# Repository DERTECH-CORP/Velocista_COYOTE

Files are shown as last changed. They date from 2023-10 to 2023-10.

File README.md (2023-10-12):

# Velocista "Coyote" - Robot Seguidor de Línea

El_COYOTE_V1

## Descripción

El velocista "Coyote" es un robot seguidor de línea de alto rendimiento diseñado para competir en desafíos de velocidad y precisión. Este repositorio contiene el firmware, el diseño de hardware electrónico y los modelos 3D relacionados con el robot Coyote. Aquí encontrarás toda la información necesaria para comprender el robot seguidor de línea Coyote.

## Características principales

- **Seguimiento de línea preciso**: Coyote utiliza los sensores ópticos QRE1113 para seguir líneas con precisión y rapidez. Su firmware incorpora algoritmos de control PID que garantizan un seguimiento suave y estable.

- **Velocidad y agilidad**: Utiliza sus motores de RPM2000 con diseño aerodinámico, El Coyote puede alcanzar altas velocidades y realizar maniobras bruscas gracias a sus ruedas anchas que le ayudan a tener mejor agarre en la pista.

- **Firmware personalizable**: El firmware del robot está escrito en lenguaje C++ y se basa en la plataforma de desarrollo ESP32. Este micricontrolador nos ayuda mucho ya que tiene antena wifi/bluetooth integrada y gracias a eso podemos debuguear y calibrar el robot sin necesidad de conectarlo a la computadora.

## Contenido del repositorio

- **/firmware**: En esta carpeta encontrarás el código fuente del firmware utilizado en Coyote. El firmware está escrito en lenguaje C++ y se basa en la plataforma de desarrollo ESP32. Incluye los algoritmos de control, la lógica de seguimiento de línea y la comunicación con los sensores y actuadores del robot ademas de la interfaz bluetooth.

- **/hardware**: Aquí se encuentran los diseños y esquemas del hardware electrónico utilizado en Coyote. Estos archivos incluyen los esquemas de conexión y los diagramas de circuitos.

- **/3D**: En esta carpeta encontrarás los modelos 3D del robot Coyote. Se pueden utilizar para visualizar, modificar y fabricar las partes físicas del robot.

¡Gracias por tu interés en Coyote!

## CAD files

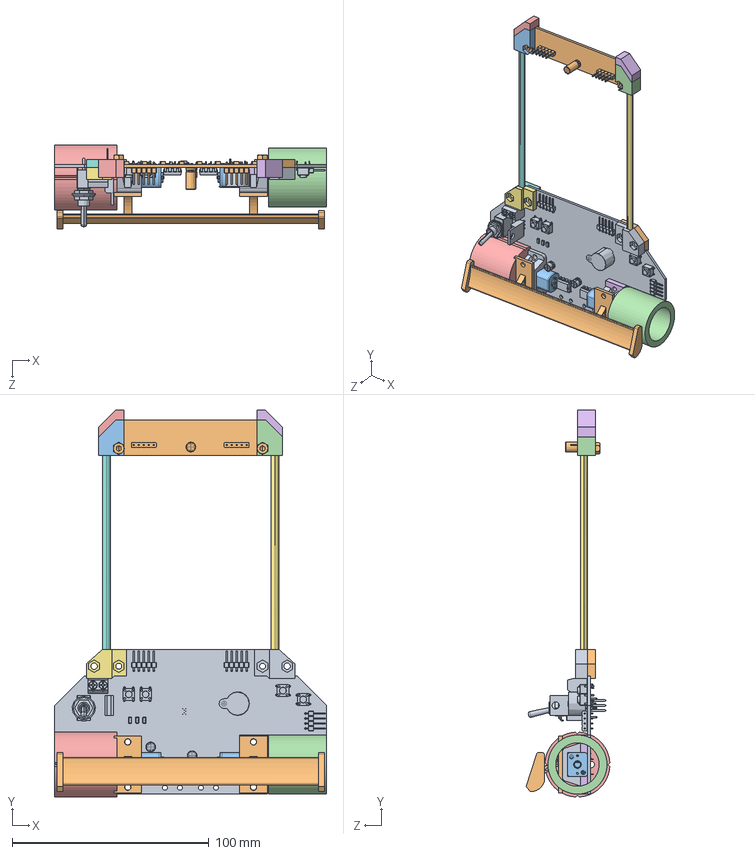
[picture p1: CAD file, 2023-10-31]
hardware_3D/COYOTE_V1.SLDASM
138.2 x 196.5 x 42.5 mm
PCB_Main_Board_COYOTE
PCB_QRE1113_Line_Sensors_x8
MicroMotor_2000RPM x 2
Cubierta_coyote x 2
Sop_VarillaDT
Sop_VarillaDB
Sop_VarillaIT
Sop_VarillaIB
Sop_SensoresD
Sop_SensoresI
Cabeza_VarillaD
Cabeza_VarillaI
VarillaI
VarillaD
Soporte_Pololu x 2
Aleron_Coyote

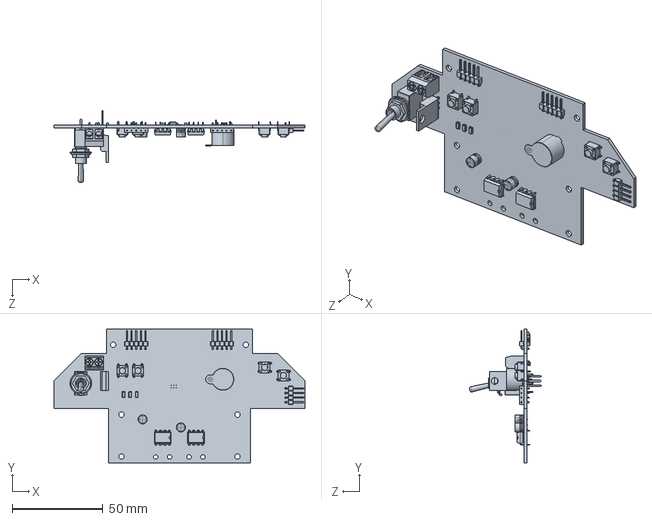
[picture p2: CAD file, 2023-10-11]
hardware_3D/PCB_Main_Board_COYOTE.SLDPRT
138.0 x 73.5 x 39.7 mm

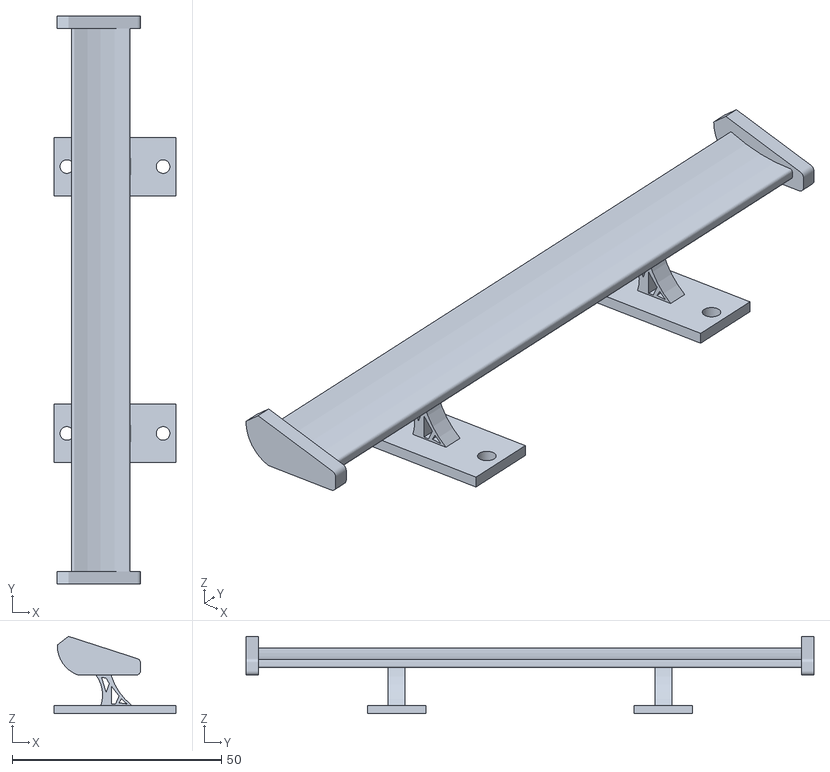
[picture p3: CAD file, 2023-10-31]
hardware_3D/Impresion/Aleron_Coyote.STL
29.1 x 135.8 x 18.5

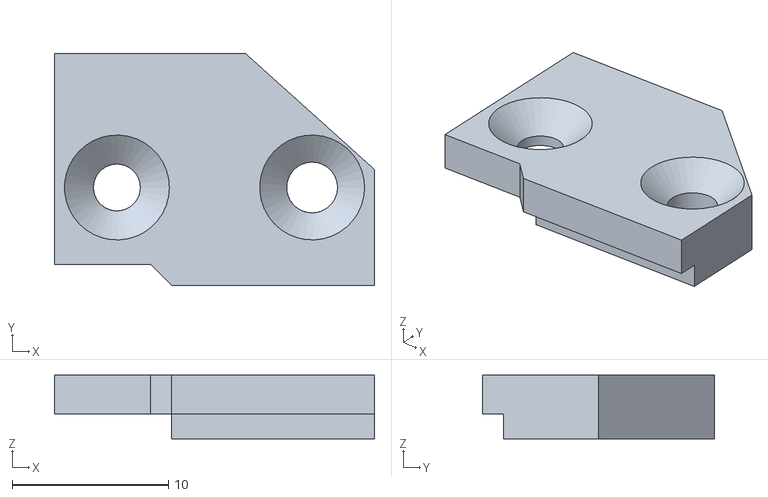
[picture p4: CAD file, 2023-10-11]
hardware_3D/Impresion/Sop_VarillaDB.STL
20.5 x 14.8 x 4.08

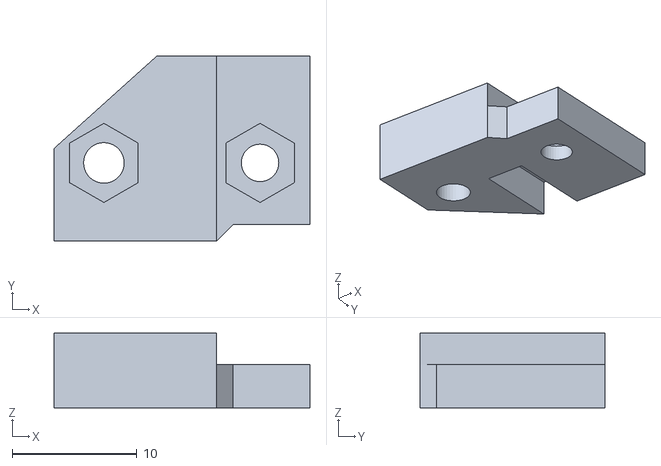
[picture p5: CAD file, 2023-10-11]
hardware_3D/Impresion/Sop_VarillaDT.STL
20.5 x 14.8 x 6.00

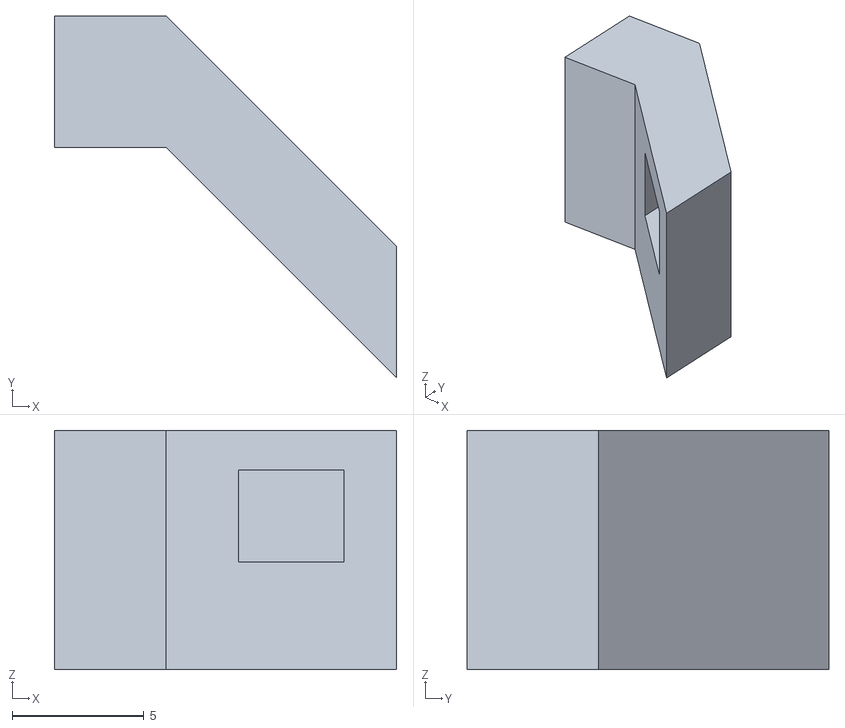
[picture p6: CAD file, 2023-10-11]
hardware_3D/Impresion/Cabeza_VarillaI.STL
13.0 x 13.7 x 9.08

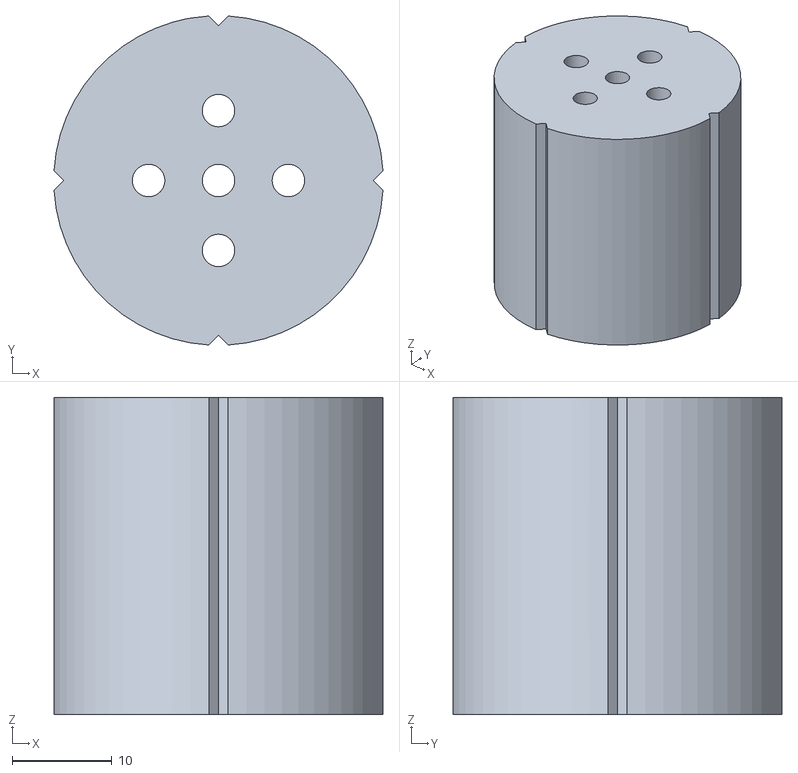
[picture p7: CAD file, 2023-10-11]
hardware_3D/Impresion/Molde_cubierta_coyote.STL
32.9 x 32.9 x 31.8

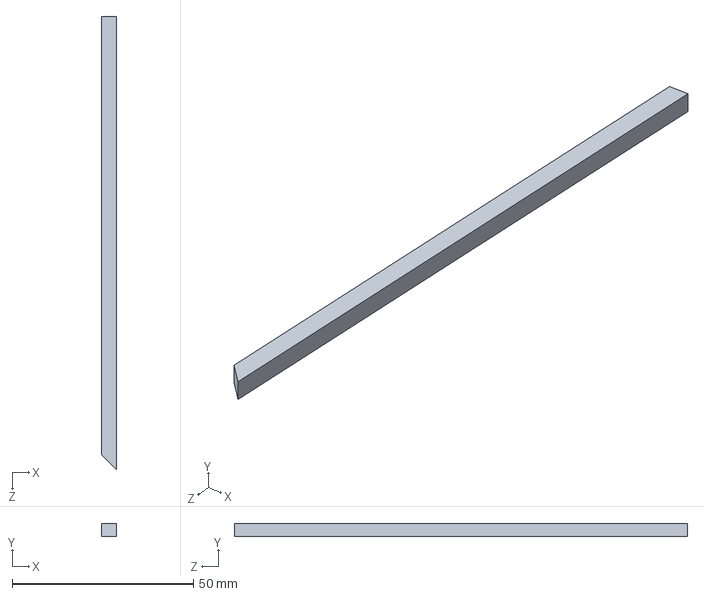
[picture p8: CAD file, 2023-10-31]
hardware_3D/VarillaD.SLDPRT
4.00 x 3.50 x 124.8 mm

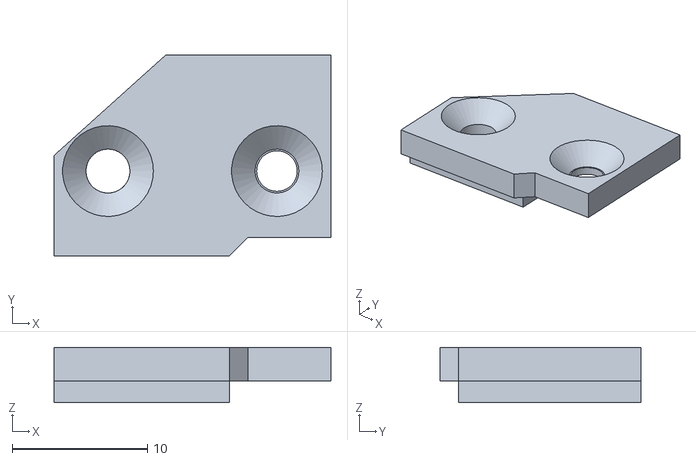
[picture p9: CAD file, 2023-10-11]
hardware_3D/Impresion/Sop_VarillaIB.STL
20.5 x 14.8 x 4.08

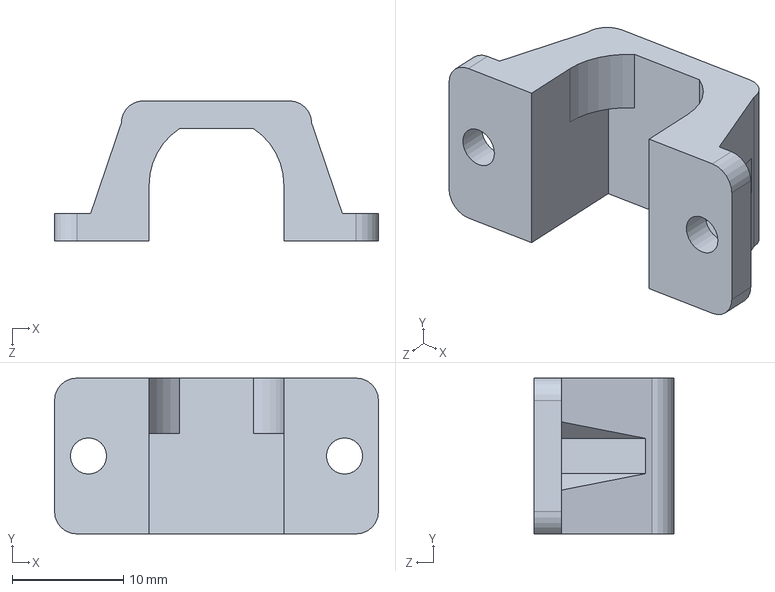
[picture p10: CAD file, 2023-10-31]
hardware_3D/Soporte_Pololu.SLDPRT
29.1 x 14.0 x 12.6 mm

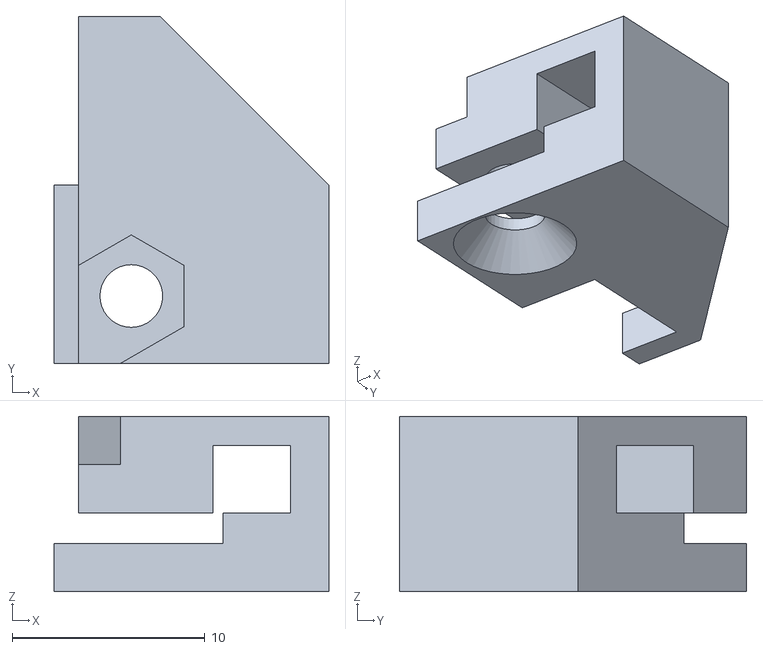
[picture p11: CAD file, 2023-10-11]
hardware_3D/Impresion/Sop_SensoresI.STL
14.2 x 18.0 x 9.08

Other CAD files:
hardware_3D/Llanta_coyote.SLDPRT
hardware_3D/Aleron_Coyote.SLDPRT
hardware_3D/VarillaI.SLDPRT
hardware_3D/Impresion/VarillaD.STL
hardware_3D/Molde_cubierta_coyote.SLDPRT
hardware_3D/Impresion/VarillaI.STL
hardware_3D/Sop_SensoresI.SLDPRT
hardware_3D/Cabeza_VarillaD.SLDPRT
hardware_3D/Cabeza_VarillaI.SLDPRT
hardware_3D/Cubierta_coyote.SLDPRT
hardware_3D/Impresion/Cabeza_VarillaD.STL
hardware_3D/Impresion/Llanta_coyote.STL
hardware_3D/Impresion/Sop_SensoresD.STL
hardware_3D/Impresion/Sop_VarillaIT.STL
hardware_3D/Impresion/Suplemento_motor.STL
hardware_3D/MicroMotor_2000RPM.SLDPRT
hardware_3D/Sop_SensoresD.SLDPRT
hardware_3D/Sop_VarillaDB.SLDPRT
hardware_3D/Sop_VarillaDT.SLDPRT
hardware_3D/Sop_VarillaIB.SLDPRT
hardware_3D/Sop_VarillaIT.SLDPRT
hardware_3D/Suplemento_motor.SLDPRT

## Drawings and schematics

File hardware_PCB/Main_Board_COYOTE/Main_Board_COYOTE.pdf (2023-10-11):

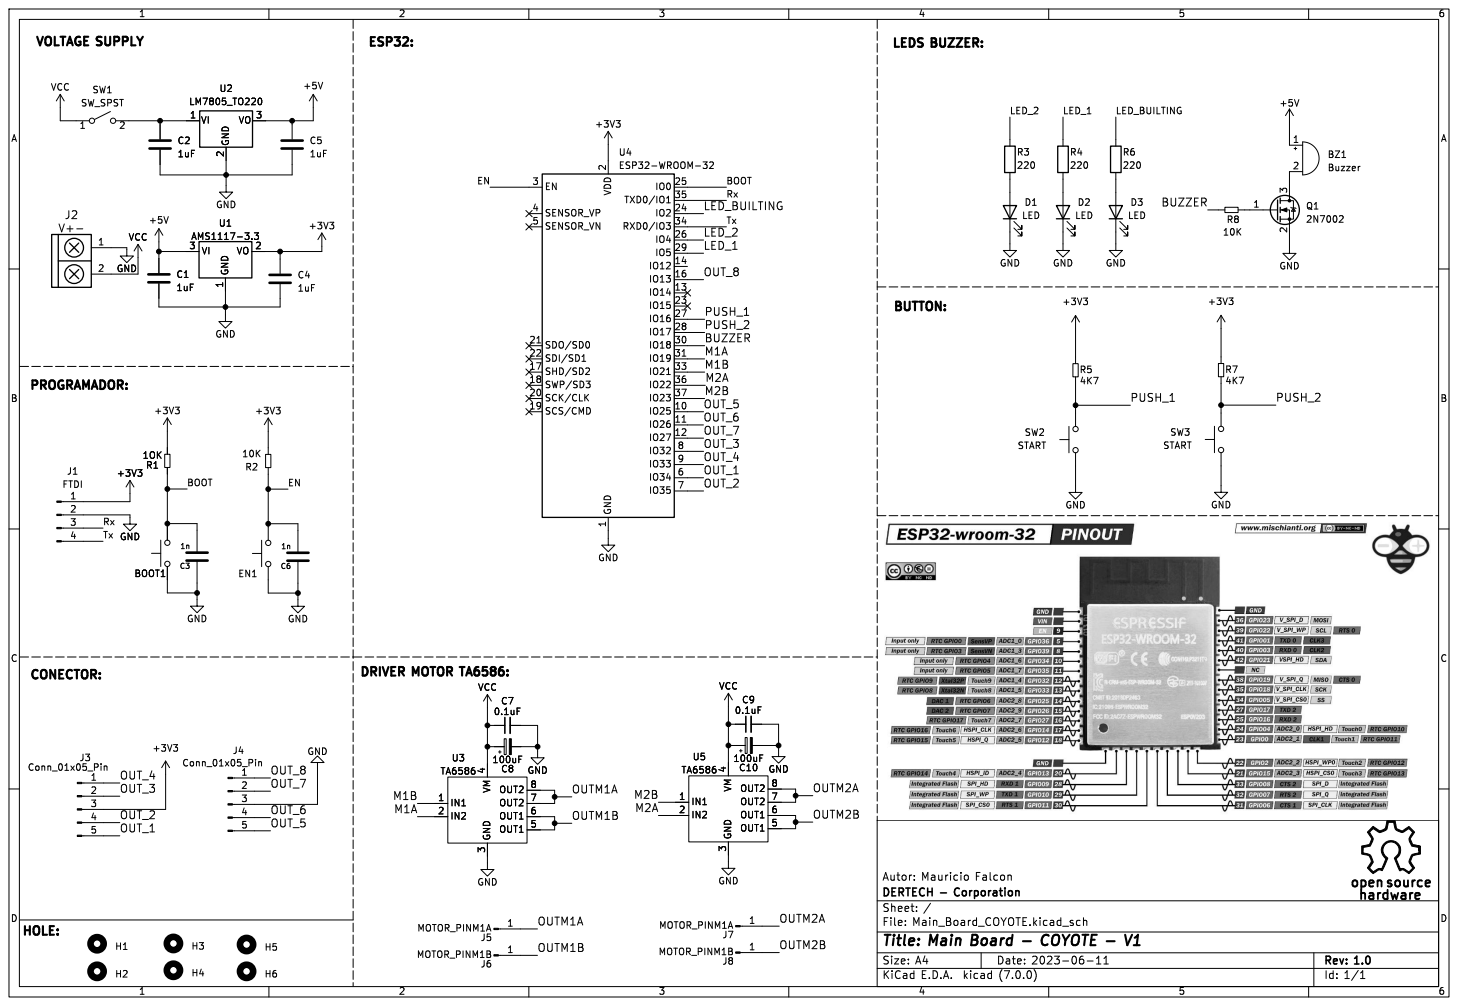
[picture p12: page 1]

2 SCK/CLK 20 SDO/SD0 21 SDI/SD1 22

Id: 1/1 Title: Main Board - COYOTE - V1

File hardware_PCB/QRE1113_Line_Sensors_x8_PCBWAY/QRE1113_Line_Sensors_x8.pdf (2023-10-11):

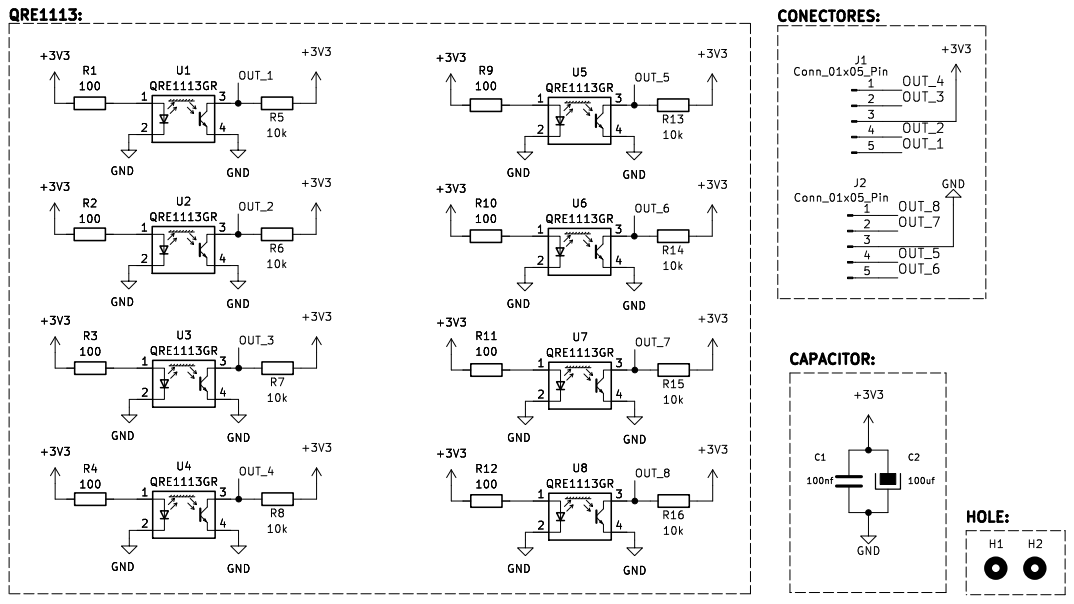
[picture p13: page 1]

Id: 1/1 Title: Line Sensors - QRE1113 x8

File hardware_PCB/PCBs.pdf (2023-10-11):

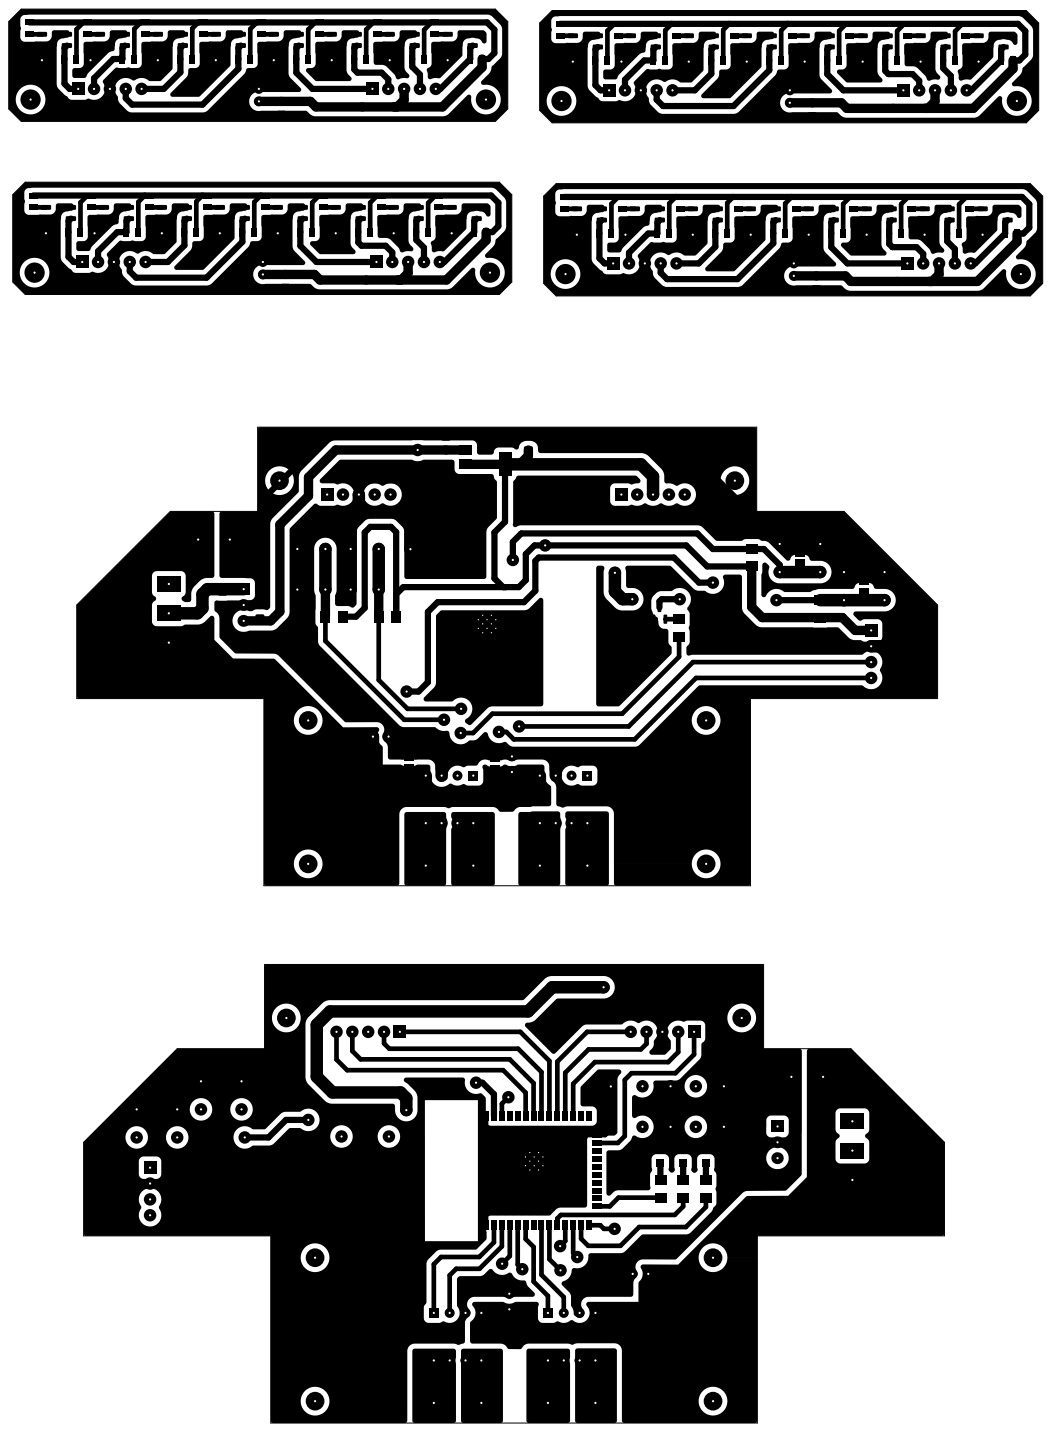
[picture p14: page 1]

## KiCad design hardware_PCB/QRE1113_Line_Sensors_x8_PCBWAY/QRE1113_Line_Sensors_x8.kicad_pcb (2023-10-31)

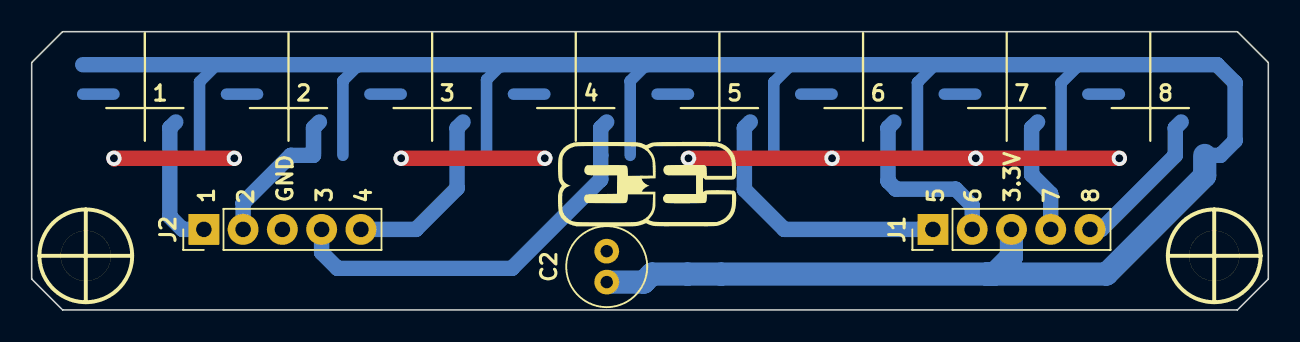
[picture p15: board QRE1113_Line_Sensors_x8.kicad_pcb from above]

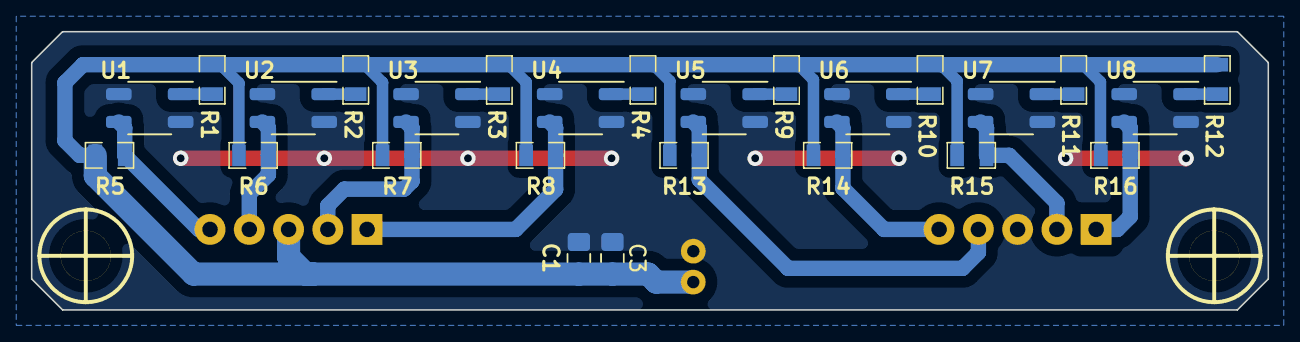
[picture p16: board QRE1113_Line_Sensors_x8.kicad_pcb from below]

Board: 2 copper layers, 80.0 x 18.0 mm, 31 parts (26 on the bottom side), 18 nets.

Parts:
C1, C3: 100nf; C_0805_2012Metric_Pad1.18x1.45mm_HandSolder
C2: 100uf; C_Radial_D5.0mm_H11.0mm_P2.00mm
H1, H2: HOLE; Separador_M3_5mm
J1, J2: Conn_01x05_Pin; PinHeader_1x05_P2.54mm_Vertical
R1, R2, R3, R4, R9, R10, R11, R12: 100; R_0805
R5, R6, R7, R8, R13, R14, R15, R16: 10k; R_0805
U1, U2, U3, U4, U5, U6, U7, U8: QRE1113GR; OnSemi_CASE100CY

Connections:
+3V3: C1.1, C2.1, C3.1, J1.3, R1.1, R2.1, R3.1, R4.1, R5.2, R6.2, R7.2, R8.2, R9.1, R10.1, R11.1, R12.1, R13.2, R14.2, R15.2, R16.2
/OUT_1: J1.5, R5.1, U1.3
/OUT_2: J1.4, R6.1, U2.3
/OUT_3: J1.2, R7.1, U3.3
/OUT_4: J1.1, R8.1, U4.3
/OUT_5: J2.4, R13.1, U5.3
/OUT_6: J2.5, R14.1, U6.3
/OUT_7: J2.2, R15.1, U7.3
/OUT_8: J2.1, R16.1, U8.3
GND: C1.2, C2.2, C3.2, J2.3, U1.2 (K), U1.4, U2.2 (K), U2.4, U3.2 (K), U3.4, U4.2 (K), U4.4, U5.2 (K), U5.4, U6.2 (K), U6.4, U7.2 (K), U7.4, U8.2 (K), U8.4
unnamed: R1.2, U1.1 (A)
unnamed: R2.2, U2.1 (A)
unnamed: R3.2, U3.1 (A)
unnamed: R4.2, U4.1 (A)
unnamed: R9.2, U5.1 (A)
unnamed: R10.2, U6.1 (A)
unnamed: R11.2, U7.1 (A)
unnamed: R12.2, U8.1 (A)

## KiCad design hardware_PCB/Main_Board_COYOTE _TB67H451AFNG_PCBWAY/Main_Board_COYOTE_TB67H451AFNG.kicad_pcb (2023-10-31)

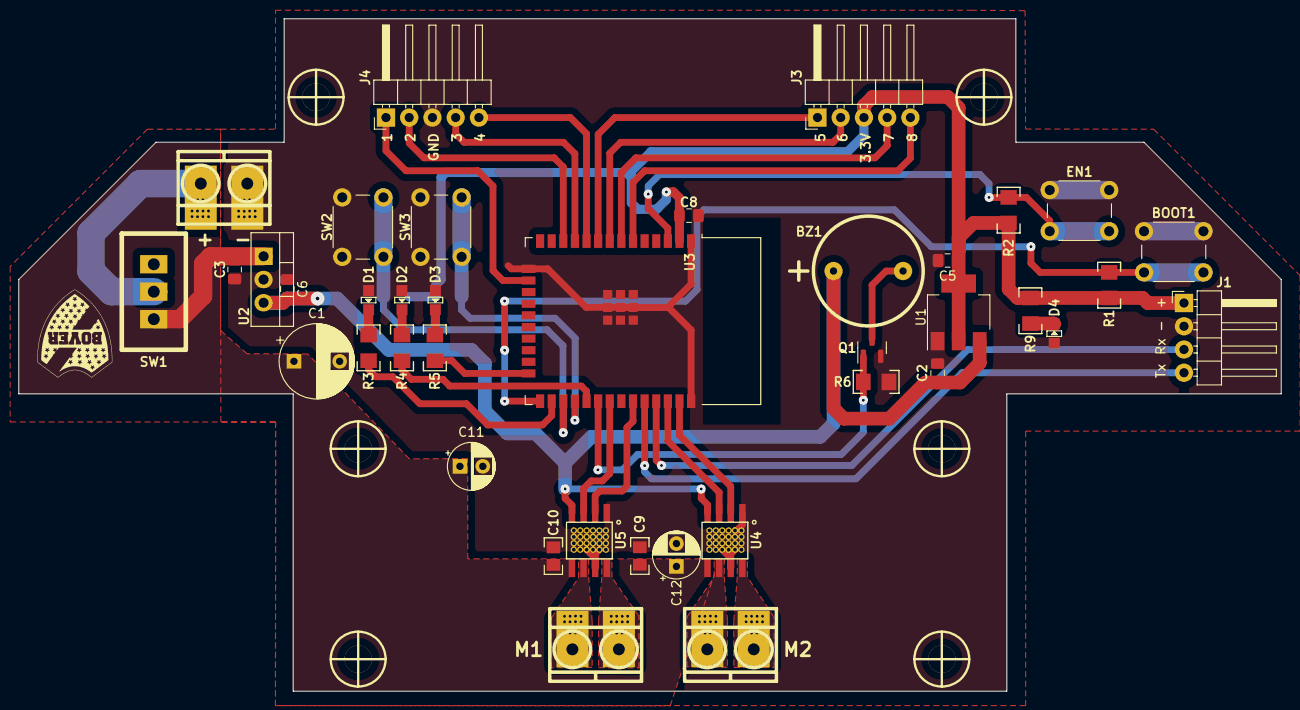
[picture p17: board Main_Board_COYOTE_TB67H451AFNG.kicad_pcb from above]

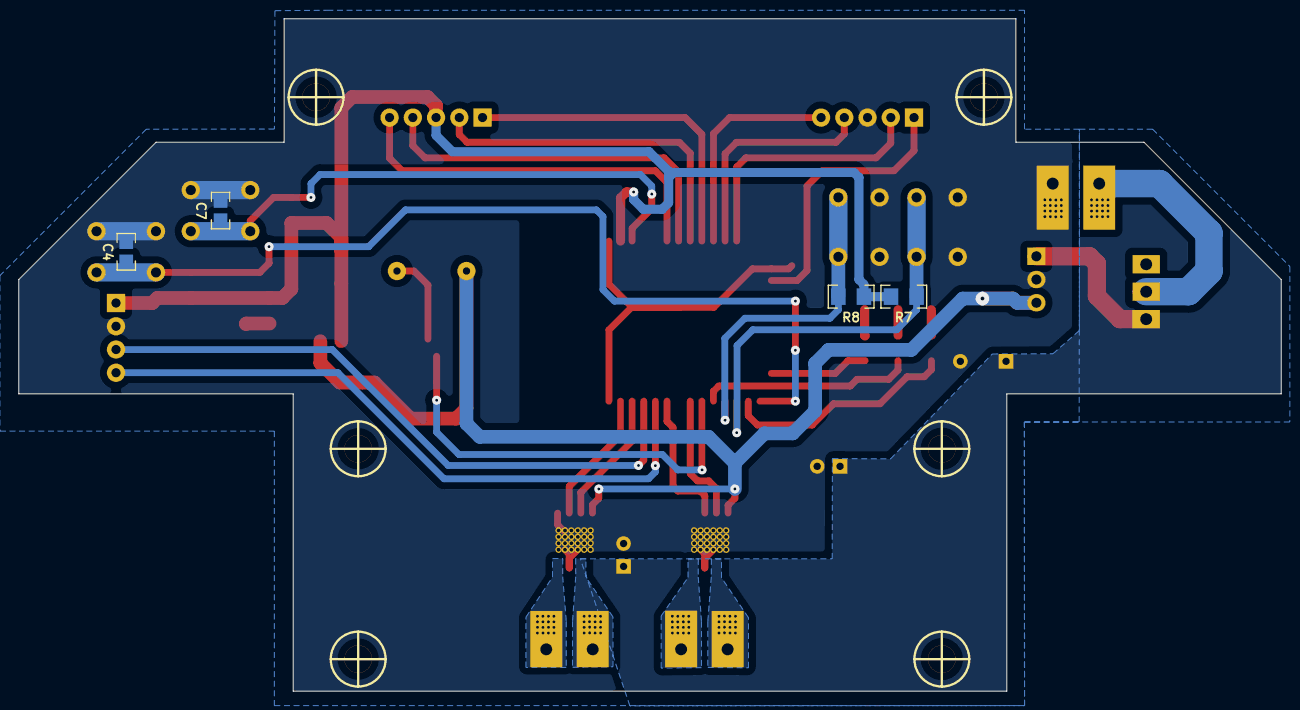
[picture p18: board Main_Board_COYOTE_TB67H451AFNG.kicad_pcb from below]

Board: 2 copper layers, 138.0 x 73.5 mm, 49 parts (4 on the bottom side), 36 nets.

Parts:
BOOT1: SW_Push; SW_PUSH_6mm_H5mm
BZ1: Buzzer; Buzzer_12mm
C1: 100uF 35V; CP_Radial_D8.0mm_P5.00mm
C2, C3, C5, C6, C8: 1uF; C_0805_2012Metric_Pad1.18x1.45mm_HandSolder
C4, C7: 1n; C_0805
C9, C10: 100nF; C_0805
C11, C12: 100uF 35V; CP_Radial_D5.0mm_P2.50mm
D1, D2, D3, D4: LED; Led_0805
EN1: SW_Push; SW_PUSH_6mm_H5mm
H1, H2, H3, H4, H5, H6: Mounting_Hole; hole_3mm
J1: FTDI; PinHeader_1x04_P2.54mm_Horizontal
J2: + -; BORNERA2_AZUL_VIAS
J3, J4: Conn_01x05_Pin; PinHeader_1x05_P2.54mm_Horizontal
J5: M2; BORNERA2_AZUL_VIAS
J6: M1; BORNERA2_AZUL_VIAS
Q1: 2N7002; SOT-23
R1: 1OK; R_1206
R2, R6: 10K; R_1206
R3, R4, R5, R9: 220; R_1206
R7, R8: 4K7; R_1206
SW1: SW_SPST; SW_SPDT_TH_Vertical
SW2: STRATEGY; SW_PUSH_6mm_H5mm
SW3: START; SW_PUSH_6mm_H5mm
U1: AMS1117-3.3; SOT-223-3_TabPin2
U2: LM7805_TO220; TO-220-3_Vertical
U3: ESP32-WROOM-32; ESP32-WROOM-32D
U4, U5: TB67H451AFNG; SSOP-8_disipa

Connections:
+3V3: C5.1, C8.2, J1.1, J3.3, R1.2, R2.2, R7.1, R8.1, R9.1, U1.2 (VO), U3.2 (VDD)
+5V: BZ1.1 (-), C2.1, C6.1, U1.3 (VI), U2.3 (VO), U4.4 (VREF), U5.4 (VREF)
/BOOT: BOOT1.2, C4.2, R1.1, U3.25 (IO0)
/BUZZER: Q1.1 (G), R6.1, U3.30 (IO18)
/EN: C7.2, EN1.2, R2.1, U3.3 (EN)
/LED_1: R4.1, U3.29 (IO5)
/LED_2: R3.1, U3.26 (IO4)
/LED_BUILTING: R5.1, U3.24 (IO2)
/M1A: U3.31 (IO19), U5.3 (IN1)
/M1B: U3.33 (IO21), U5.2 (IN2)
/M2A: U3.36 (IO22), U4.3 (IN1)
/M2B: U3.37 (IO23), U4.2 (IN2)
/OUT_1: J3.5, U3.6 (IO34)
/OUT_2: J3.4, U3.7 (IO35)
/OUT_3: J3.2, U3.8 (IO32)
/OUT_4: J3.1, U3.9 (IO33)
/OUT_5: J4.5, U3.10 (IO25)
/OUT_6: J4.4, U3.11 (IO26)
/OUT_7: J4.2, U3.12 (IO27)
/OUT_8: J4.1, U3.16 (IO13)
/PUSH_1: R7.2, SW2.2, U3.27 (IO16)
/PUSH_2: R8.2, SW3.2, U3.28 (IO17)
/Rx: J1.3, U3.35 (TXD0/IO1)
/Tx: J1.4, U3.34 (RXD0/IO3)
/VIN: J2.2, SW1.1 (A)
GND: BOOT1.1, C1.2, C2.2, C3.2, C4.1, C5.2, C6.2, C7.1, C8.1, C9.2, C10.2, C11.2, C12.2, D1.1 (K), D2.1 (K), D3.1 (K), D4.1 (K), EN1.1, J1.2, J2.1, J4.3, Q1.2 (S), R6.2, SW2.1, SW3.1, U1.1 (GND), U2.2 (GND), U3.1 (GND), U3.15 (GND), U3.38 (GND), U3.39 (GND), U4.1 (GND), U4.7 (RS), U5.1 (GND), U5.7 (RS)
unnamed: BZ1.2 (+), Q1.3 (D)
unnamed: D1.2 (A), R3.2
unnamed: D2.2 (A), R4.2
unnamed: D3.2 (A), R5.2
unnamed: D4.2 (A), R9.2
unnamed: J5.1, U4.6 (OUT1)
unnamed: J5.2, U4.8 (OUT2)
unnamed: J6.1, U5.6 (OUT1)
unnamed: J6.2, U5.8 (OUT2)
VCC: C1.1, C3.1, C9.1, C10.1, C11.1, C12.1, SW1.2 (B), U2.1 (VI), U4.5 (VM), U5.5 (VM)

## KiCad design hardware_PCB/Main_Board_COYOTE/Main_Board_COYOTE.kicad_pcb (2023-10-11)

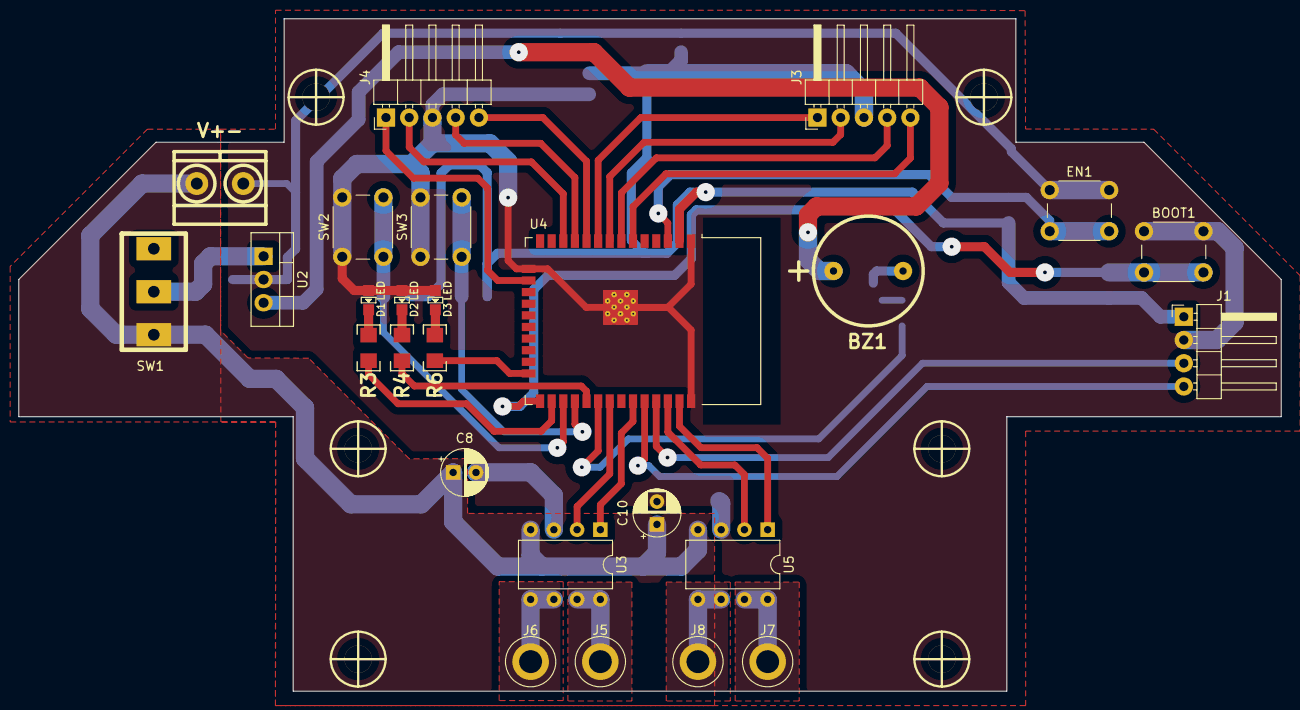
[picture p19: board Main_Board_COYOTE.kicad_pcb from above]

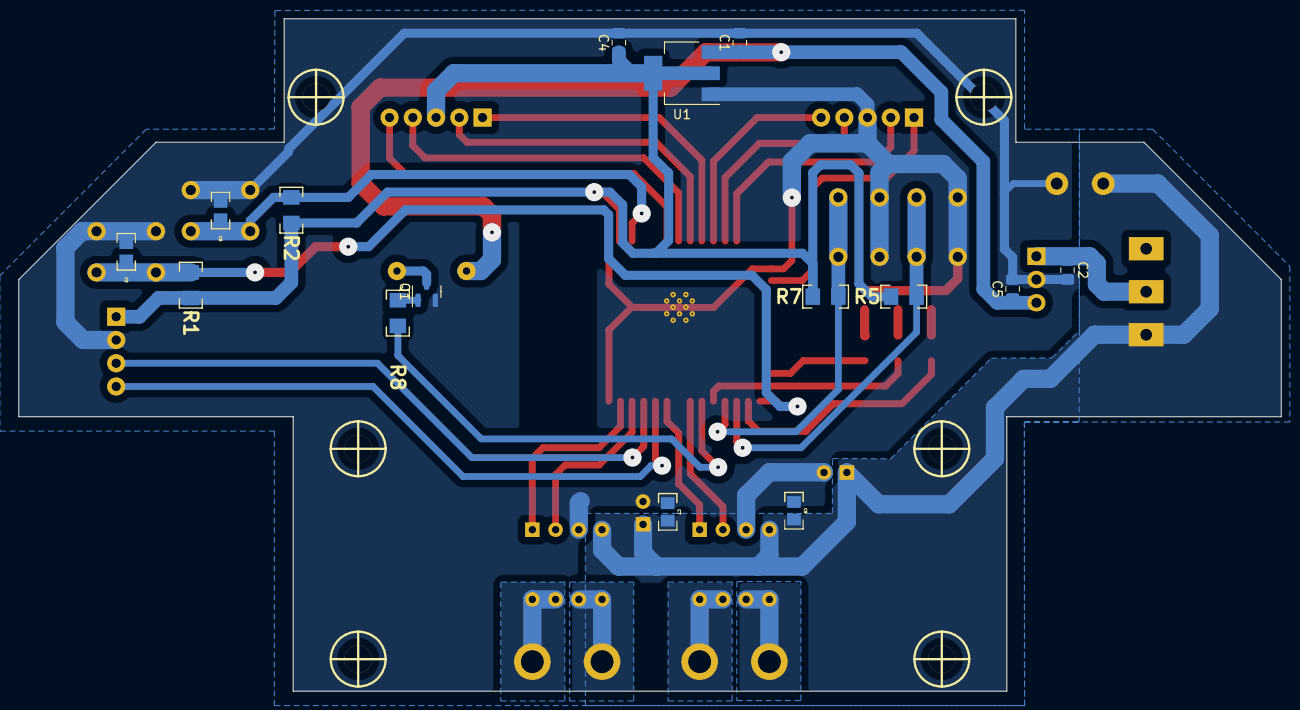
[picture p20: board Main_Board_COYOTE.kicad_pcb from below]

Board: 2 copper layers, 138.0 x 73.5 mm, 47 parts (15 on the bottom side), 36 nets.

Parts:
BOOT1: SW_Push; SW_PUSH_6mm_H5mm
BZ1: Buzzer; Buzzer_12mm
C1, C2, C4, C5: 1uF; C_0805_2012Metric_Pad1.18x1.45mm_HandSolder
C3, C6: 1n; C_0805
C7, C9: 0.1uF; C_0805
C8, C10: 100uF; CP_Radial_D5.0mm_P2.50mm
D1, D2, D3: LED; Led_0805
EN1: SW_Push; SW_PUSH_6mm_H5mm
H1, H2, H3, H4, H5, H6: Mounting_Hole; hole_3mm
J1: FTDI; PinHeader_1x04_P2.54mm_Horizontal
J2: V+-; BORNERA2_AZUL
J3, J4: Conn_01x05_Pin; PinHeader_1x05_P2.54mm_Horizontal
J5, J7: MOTOR_PINM1A; Banana_Jack_1Pin
J6, J8: MOTOR_PINM1B; Banana_Jack_1Pin
Q1: 2N7002; SOT-23
R1: 1OK; R_1206
R2, R8: 10K; R_1206
R3, R4, R6: 220; R_1206
R5, R7: 4K7; R_1206
SW1: SW_SPST; SW_SPDT_TH_Vertical
SW2, SW3: START; SW_PUSH_6mm_H5mm
U1: AMS1117-3.3; SOT-223-3_TabPin2
U2: LM7805_TO220; TO-220-3_Vertical
U3, U5: TA6586; DIP-8_W7.62mm
U4: ESP32-WROOM-32; ESP32-WROOM-32D

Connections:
+3V3: C4.1, J1.1, J3.3, R1.2, R2.2, R5.1, R7.1, U1.2 (VO), U4.2 (VDD)
+5V: BZ1.1 (-), C1.1, C5.1, U1.3 (VI), U2.3 (VO)
/BOOT: BOOT1.2, C3.2, R1.1, U4.25 (IO0)
/BUZZER: R8.2, U4.30 (IO18)
/EN: C6.2, EN1.2, R2.1, U4.3 (EN)
/LED_1: R4.1, U4.29 (IO5)
/LED_2: R3.1, U4.26 (IO4)
/LED_BUILTING: R6.1, U4.24 (IO2)
/M1A: U3.2 (IN2), U4.31 (IO19)
/M1B: U3.1 (IN1), U4.33 (IO21)
/M2A: U4.36 (IO22), U5.2 (IN2)
/M2B: U4.37 (IO23), U5.1 (IN1)
/OUTM1A: J5.1, U3.7 (OUT2), U3.8 (OUT2)
/OUTM1B: J6.1, U3.5 (OUT1), U3.6 (OUT1)
/OUTM2A: J7.1, U5.7 (OUT2), U5.8 (OUT2)
/OUTM2B: J8.1, U5.5 (OUT1), U5.6 (OUT1)
/OUT_1: J3.5, U4.6 (IO34)
/OUT_2: J3.4, U4.7 (IO35)
/OUT_3: J3.2, U4.8 (IO32)
/OUT_4: J3.1, U4.9 (IO33)
/OUT_5: J4.5, U4.10 (IO25)
/OUT_6: J4.4, U4.11 (IO26)
/OUT_7: J4.2, U4.12 (IO27)
/OUT_8: J4.1, U4.16 (IO13)
/PUSH_1: R5.2, SW2.2, U4.27 (IO16)
/PUSH_2: R7.2, SW3.2, U4.28 (IO17)
/Rx: J1.3, U4.35 (TXD0/IO1)
/Tx: J1.4, U4.34 (RXD0/IO3)
GND: BOOT1.1, C1.2, C2.2, C3.1, C4.2, C5.2, C6.1, C7.2, C8.2, C9.2, C10.2, D1.1 (K), D2.1 (K), D3.1 (K), EN1.1, J1.2, J2.1, J4.3, Q1.2 (S), SW2.1, SW3.1, U1.1 (GND), U2.2 (GND), U3.3 (GND), U4.1 (GND), U4.15 (GND), U4.38 (GND), U4.39 (GND), U5.3 (GND)
unnamed: BZ1.2 (+), Q1.3 (D)
unnamed: D1.2 (A), R3.2
unnamed: D2.2 (A), R4.2
unnamed: D3.2 (A), R6.2
unnamed: Q1.1 (G), R8.1
unnamed: C2.1, SW1.2 (B), U2.1 (VI)
VCC: C7.1, C8.1, C9.1, C10.1, J2.2, SW1.1 (A), U3.4 (VM), U5.4 (VM)

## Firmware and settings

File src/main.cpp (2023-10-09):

#include "BluetoothSerial.h"
#include <QTRSensors.h>
#include <Motor.h>

#if !defined(CONFIG_BT_ENABLED) || !defined(CONFIG_BLUEDROID_ENABLED)
#error Bluetooth is not enabled! Please run `make menuconfig` to and enable it
#endif

// boleano para que se ejecute el pid
bool run = false;

#define M1A 19
#define M1B 21
#define M2A 23
#define M2B 22
#define M1A_CHANEL 12
#define M1B_CHANEL 14
#define M2A_CHANEL 13
#define M2B_CHANEL 15

#define BUTTON 16

// valores pre definidos

// para sumar o restar velocidades
#define VALUE_5 5

// para sumar o restar el gate
#define VALUE_500 500

// para sumar o restas a
//  kp, ki, kd
#define VALUE_0_1 0.1
#define VALUE_0_01 0.01

#define COMPENSATION_PWM 5

int proportional = 0;
int derivative = 0;
int integral = 0;
int lastErr = 0;

// variables configurables para el pid
float kp = 0.03;
float ki = 0;
float kd = 0.06;

float speed = 0;

// velocidad crucero es la velocidad que se
// utiliza para el pid y es el pico en rectas
int velocity = 120;

int velocityTurn = 80;

// floats para almacenar los valores de los pid
// de cada motor
float pidLeft = 0;
float pidRight = 0;

// estos son los valores maximos y minimos
// de los motores cuando se le aplica el pid
int maxSpeed = 150;
int minSpeed = 0;

// gete es la barrera que sirve como flag
// para las condicionales de giro
int gateLeft = 2500;
int gateRight = 5000;

// lock : es el pwm  que va a
// usar el motor para frenar
int lockLeft = 85;
int lockRight = 70;

BluetoothSerial SerialBT;

QTRSensors qtr;

MOTOR *motorLeft = new MOTOR(M1B, M1A, M1B_CHANEL, M1A_CHANEL);

MOTOR *motorRight = new MOTOR(M2A, M2B, M2B_CHANEL, M2A_CHANEL);

// setpoint : es el punto en el que se desea
int setpoint = 3500;

const uint8_t SensorCount = 8;
uint16_t sensorValues[SensorCount];

int Led = 5;
int LedB = 2;

void calibration()
{
  qtr.setTypeAnalog();
  qtr.setSensorPins((const uint8_t[]){
                        13, 27, 25, 26, 33, 32, 35, 34},
                    SensorCount);

  delay(500);
  pinMode(Led, OUTPUT);
  digitalWrite(Led, HIGH);
  for (uint16_t i = 0; i < 500; i++)
  {
    qtr.calibrate();
  }
  digitalWrite(Led, LOW);
}

// funcion que nos va a retornar la posicion
//  de la linea
int getPosition()
{
  int position = qtr.readLineWhite(sensorValues);
  return position;
}



void PID()
{
  int position = getPosition();

  proportional = position - setpoint;

  derivative = proportional - lastErr;

  integral += proportional;

  speed = (proportional * kp) + (derivative * kd) + (integral * ki);

  lastErr = proportional;

  pidLeft = (velocity + speed + COMPENSATION_PWM);
  pidRight = (velocity - speed);

  if (pidLeft > maxSpeed + COMPENSATION_PWM)
    pidLeft = maxSpeed + COMPENSATION_PWM;
  else if (pidLeft < minSpeed)
    pidLeft = minSpeed;

  if (pidRight < minSpeed)
    pidRight = minSpeed;
  else if (pidRight > maxSpeed)
    pidRight = maxSpeed;

  if (position >= gateRight)
  {

    motorLeft->GoAvance(velocityTurn);
    motorRight->GoBack(lockRight);

    
  }
  else if (position <= gateLeft)
  {

    motorLeft->GoBack(lockLeft);
    motorRight->GoAvance(velocityTurn);

    
  }
  else
  {
    motorLeft->GoAvance(pidLeft);
    motorRight->GoAvance(pidRight);
  }
}

// funcion que imprime un menu por bluetooth
void printOptions()
{
  // clean the serial
  for (int i = 0; i < 10; i++)
  {
    SerialBT.println("");
  }

  SerialBT.println("Configuracion Actual:");

  SerialBT.print("- KP = ");
  SerialBT.println(kp);

  SerialBT.print("- KI = ");
  SerialBT.println(ki);

  SerialBT.print("- KD = ");
  SerialBT.println(kd);

  SerialBT.print("- maxSpeed = ");
  SerialBT.println(maxSpeed);

  SerialBT.print("- lockLeft = ");
  SerialBT.println(lockLeft);

  SerialBT.print("- lockRight = ");
  SerialBT.println(lockRight);

  SerialBT.print("- gateLeft = ");
  SerialBT.println(gateLeft);

  SerialBT.print("- gateRight = ");
  SerialBT.println(gateRight);

  SerialBT.print("- velocityTurn = ");
  SerialBT.println(velocityTurn);

  SerialBT.println(" (K) KP + 0.1 / (L) KP - 0.1");
  SerialBT.println(" (Q) KP + 0.01 / (W) KP - 0.01");

  SerialBT.println(" (R) KI + 0.1 / (T) KI - 0.1");
  SerialBT.println(" (U) KI + 0.01 / (I) KI - 00.1");

  SerialBT.println(" (Z) KD + 0.1 / (X) KD - 0.1");
  SerialBT.println(" (G) KD + 0.01 / (H) KD - 00.1");

  SerialBT.println(" (1) lockLeft + 5 / (2) lockLeft - 5");
  SerialBT.println(" (3) lockRight + 5 / (4) lockRight - 5");

  SerialBT.println(" (5) maxSpeed + 5 / (6) maxSpeed - 5");

  SerialBT.println(" (7) gateLeft + 500 / (8) gateLeft - 500");
  SerialBT.println(" (9) gateRight + 500 / (0) gateRight - 500");

  SerialBT.println(" (+) velocityTurn + 1 / (-) velocityTurn - 1");

  SerialBT.println(" (F) para ver la posicion");
}

void menuBT()
{
  if (SerialBT.available())
  {
    char Menssage = SerialBT.read();
    switch (Menssage)
    {
    case 'M':
    {
      printOptions();
      break;
    }
    case 'A':
    {
      run = true;
      break;
    }
    case 'B':
    {
      run = false;
      break;
    }
    case 'K':
    {
      kp += VALUE_0_1;
      printOptions();
      break;
    }
    case 'L':
    {
      kp -= VALUE_0_1;
      printOptions();
      break;
    }
    case 'Q':
    {
      kp += VALUE_0_01;
      printOptions();
      break;
    }
    case 'W':
    {
      kp -= VALUE_0_01;
      printOptions();
      break;
    }

    case 'R':
    {
      ki += VALUE_0_1;
      printOptions();
      break;
    }
    case 'T':
    {
      ki -= VALUE_0_1;
      printOptions();
      break;
    }
    case 'U':
    {
      ki += VALUE_0_01;
      printOptions();
      break;
    }
    case 'I':
    {
      ki -= VALUE_0_01;
      printOptions();
      break;
    }

    case 'Z':
    {
      kd += VALUE_0_1;
      printOptions();
      break;
    }
    case 'X':
    {
      kd -= VALUE_0_1;
      printOptions();
      break;
    }
    case 'G':
    {
      kd += VALUE_0_01;
      printOptions();
      break;
    }
    case 'H':
    {
      kd -= VALUE_0_01;
      printOptions();
      break;
    }
    case 'F':
    {
      SerialBT.println(getPosition());
      break;
    }
    case '1':
    {
      lockLeft += VALUE_5;
      printOptions();
      break;
    }
    case '2':
    {
      lockLeft -= VALUE_5;
      printOptions();
      break;
    }
    case '3':
    {
      lockRight += VALUE_5;
      printOptions();
      break;
    }
    case '4':
    {
      lockRight -= VALUE_5;
      printOptions();
      break;
    }
    case '5':
    {
      maxSpeed += VALUE_5;
      printOptions();
      break;
    }
    case '6':
    {
      maxSpeed -= VALUE_5;
      printOptions();
      break;
    }
    case '7':
    {
      gateLeft += VALUE_500;
      printOptions();
      break;
    }
    case '8':
    {
      gateLeft -= VALUE_500;
      printOptions();
      break;
    }
    case '9':
    {
      gateRight += VALUE_500;
      printOptions();
      break;
    }
    case '0':
    {
      gateRight -= VALUE_500;
      printOptions();
      break;
    }
    case '+':
    {
      velocityTurn += 1;
      printOptions();
      break;
    }
    case '-':
    {
      velocityTurn -= 1;
      printOptions();
      break;
    }

    default:
      break;
    }
  }
}

void setup()
{
  pinMode(Led, OUTPUT);
  calibration();
  pinMode(LedB, OUTPUT);
  pinMode(BUTTON, INPUT);
  digitalWrite(LedB, HIGH);
}

bool isPress = false;

void loop()
{
  if (digitalRead(BUTTON) == LOW) isPress = true;

  if (isPress)
  {
    PID();
  }
}

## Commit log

2023-06-11 Creacion de la carpeta hardware
    [Main_Board_COYOTE.kicad_pcb, Main_Board_COYOTE.kicad_sch]
2023-07-30 Creacion del PCB de sensores QRE1113, y desarrollo del mismo
    [Main_Board_COYOTE.kicad_sch, QRE1113_Line_Sensors_x8.kicad_pcb, QRE1113_Line_Sensors_x8.kicad_sch]
2023-08-02 Creacion del SCH de la main board
    [Main_Board_COYOTE.kicad_pcb, Main_Board_COYOTE.kicad_sch]
2023-08-02 Creacion croquis Velocista
    [Main_Board_COYOTE.kicad_pcb, Main_Board_COYOTE.kicad_sch]
2023-08-04 Creacion finalizacion del croquis velocista
    [Main_Board_COYOTE.kicad_pcb, Main_Board_COYOTE.kicad_sch]
2023-08-04 Edicion SCh y PCB de la main board
    [Main_Board_COYOTE.kicad_pcb, Main_Board_COYOTE.kicad_sch]
2023-08-05 SCH del velocista terminado
    [Main_Board_COYOTE.kicad_pcb, Main_Board_COYOTE.kicad_sch]
2023-08-06 Ultimas mejoras del PCB main e inicio del modelo 3D
    [COYOTE_V1.SLDASM, Concepto_Llanta.SLDPRT, Main_Board_COYOTE.SLDPRT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]
2023-08-06 Terminados los PCBs
    [Main_Board_COYOTE.kicad_pcb, Main_Board_COYOTE.kicad_sch, PCB_Main_Board_COYOTE.SLDPRT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]
2023-08-07 Se diseño el modelo 3D de la rueda
    [COYOTE_V1.SLDASM, Cubierta_coyote.SLDPRT, Llanta_coyote.SLDPRT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]
2023-08-17 Creacion del soporte de varillas
    [COYOTE_V1.SLDASM, PCB_Main_Board_COYOTE.SLDPRT, Pieza1.SLDPRT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]
2023-08-17 Se crearon los modelos 3D de los sportes de placas, varillas y motores
    [COYOTE_V1.SLDASM, Cabeza_VarillaD.SLDPRT, Cabeza_VarillaD.STL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]
2023-09-08 Add library Motor version Esp
2023-09-14 define sensors
2023-09-14 calibration and getPosition
2023-09-14 Fix error sensors
2023-09-22 update lib MOTOR
2023-09-22 Test with bluetooth and motors
2023-09-24 case menu PID
2023-10-03 PID v6
2023-10-16 update pid
2023-10-27 ultimo de lo ultimo
2023-10-31 Agregue los PCB para fabricar
    [Aleron_Coyote.SLDPRT, Aleron_Coyote.STL, COYOTE_V1.SLDASM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]
